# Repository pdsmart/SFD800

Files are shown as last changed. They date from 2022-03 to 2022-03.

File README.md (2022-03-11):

# SFD800
A Floppy Disk Interface card for the Sharp MZ series of machines (MZ-80B/MZ-800/MZ-1500/MZ-2000/MZ-2200).

This project reproduces an iconic floppy disk interface card from the 1980's. As floppy disks were expensive in those days, not many interface cards or floppy 
disk drives existed and even fewer survived. As the Sharp MZ series machines, like many of the old computers, are still used and in many ways making a comeback,
the need for a floppy disk interface is needed in order to use the machines.

Please see my website, https://eaw.app for more documentation and any recent updates. This interface has been well tested and used in many machines, a validated design.

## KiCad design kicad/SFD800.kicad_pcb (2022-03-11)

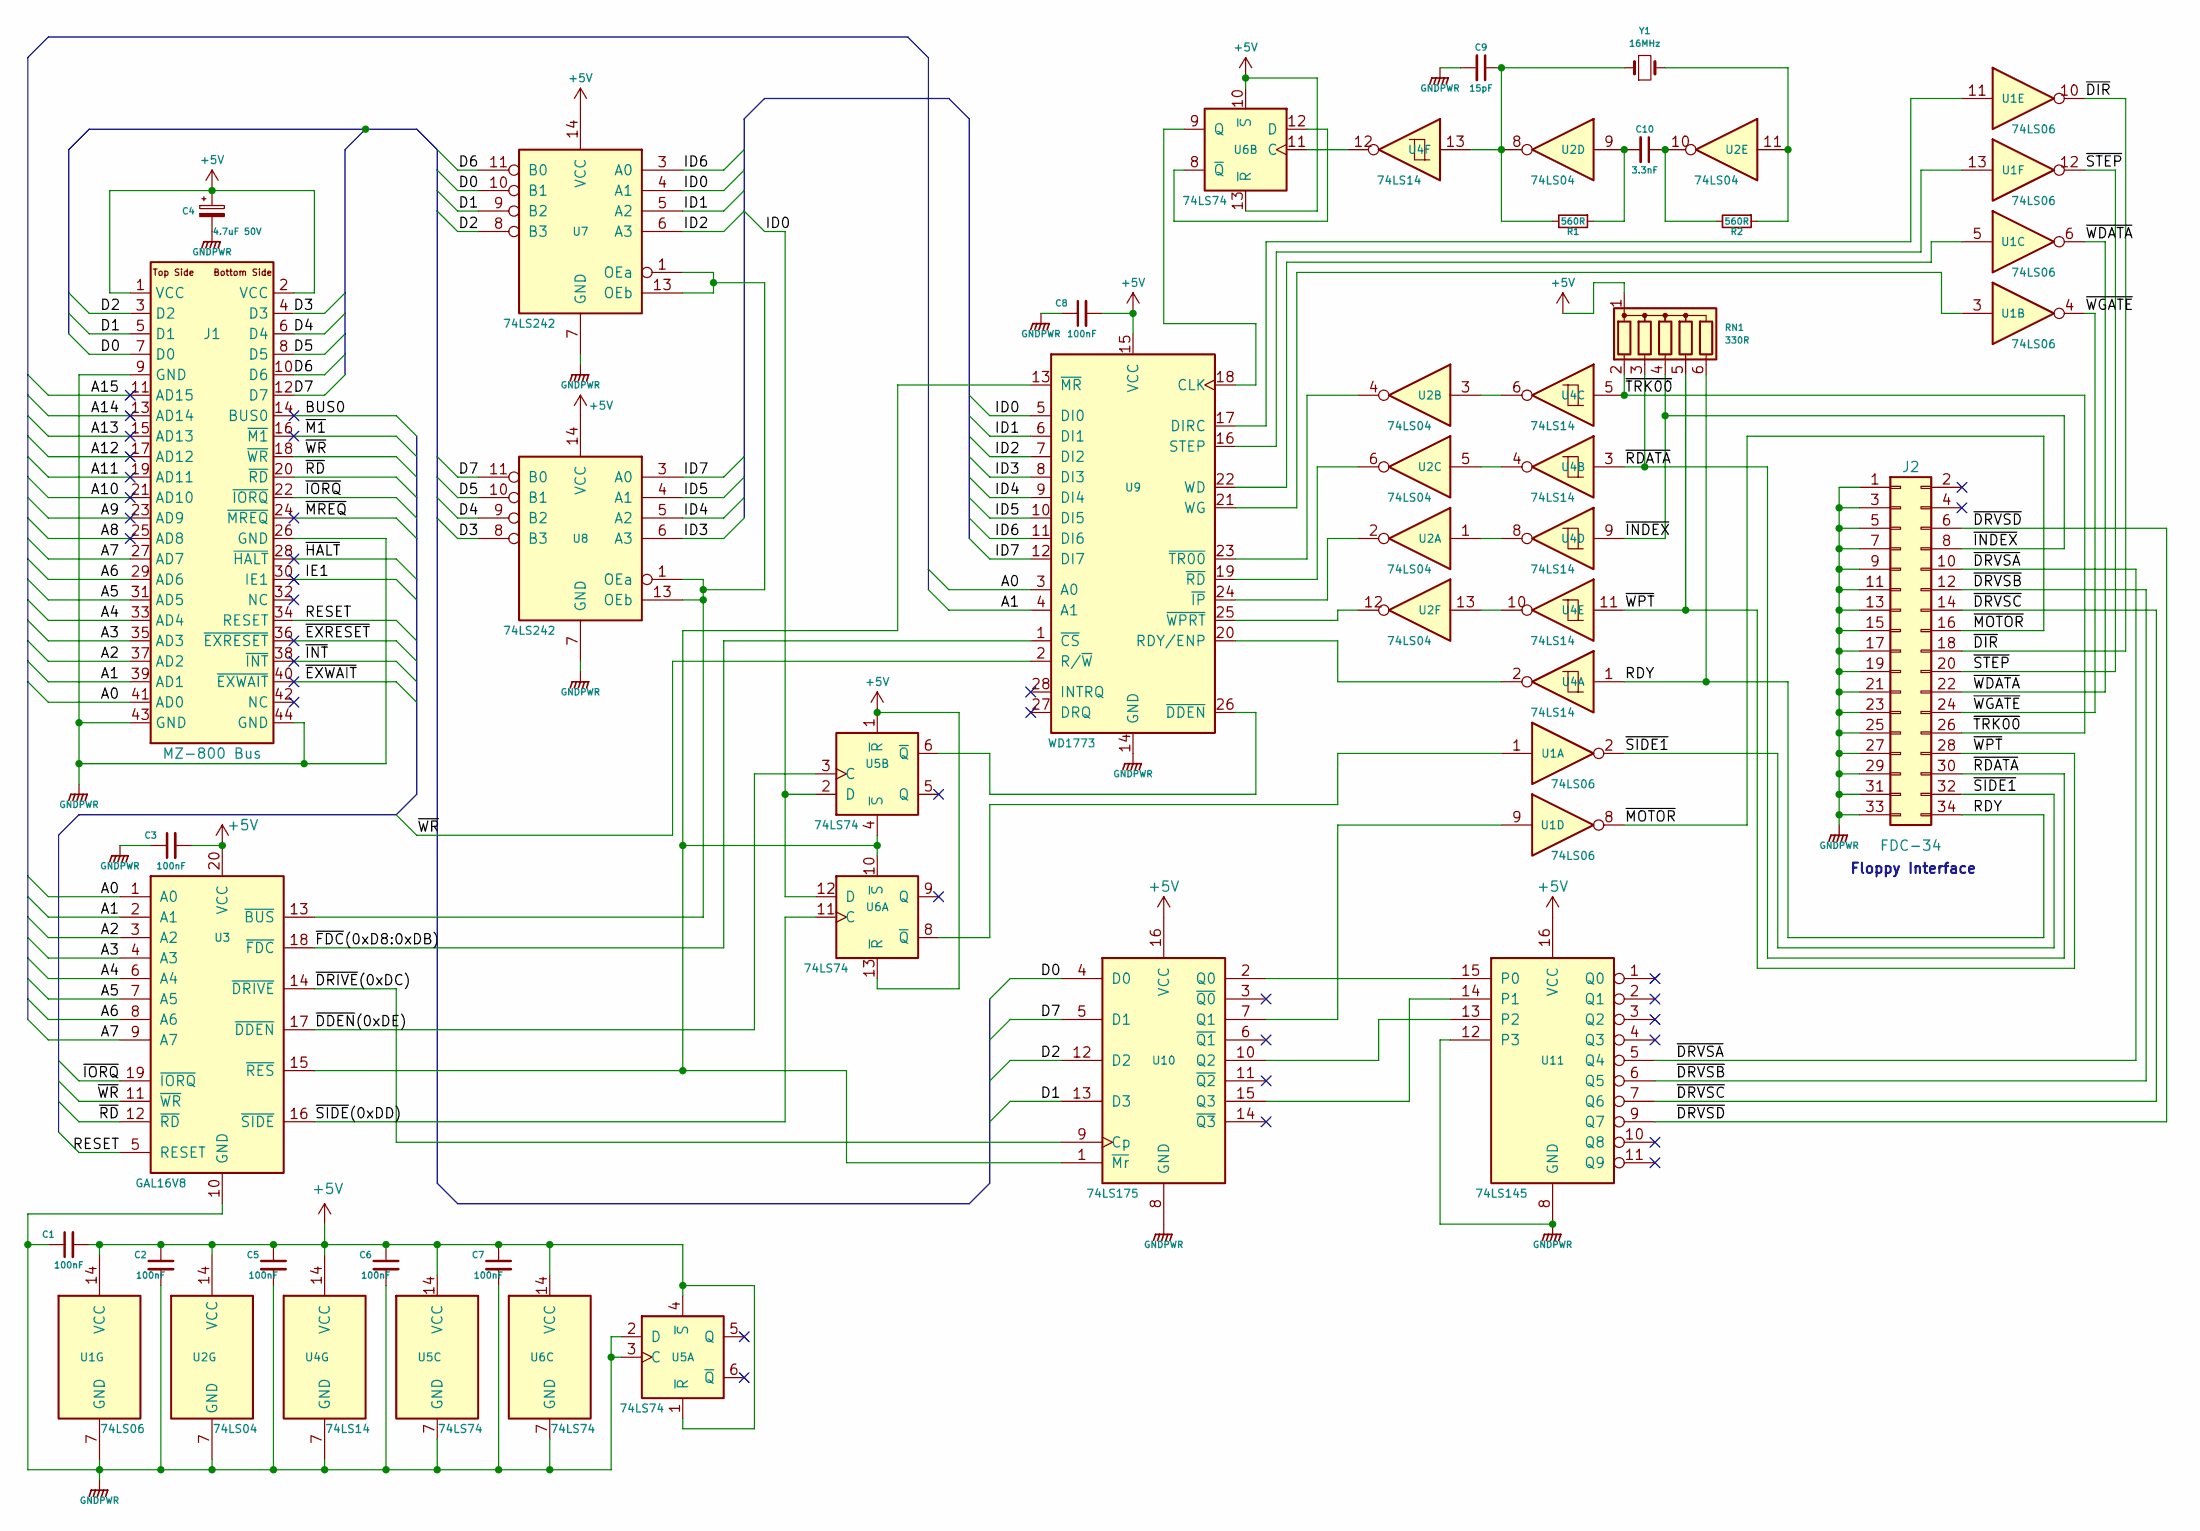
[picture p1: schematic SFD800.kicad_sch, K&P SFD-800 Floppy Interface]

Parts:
C1, C2, C3, C5, C6, C7, C8: 100nF; C_Disc_D5.0mm_W2.5mm_P2.50mm
C4: 4.7uF 50V; C_Disc_D5.0mm_W2.5mm_P2.50mm
C9: 15pF; C_Disc_D5.0mm_W2.5mm_P2.50mm
C10: 3.3nF; C_Disc_D5.0mm_W2.5mm_P2.50mm
J1: MZ-800 Bus; BUS_MZ800
J2: FDC-34; IDC-Header_2x17_P2.54mm_Horizontal_Lock_SFD800
R1, R2: 560R; R_Axial_DIN0204_L3.6mm_D1.6mm_P5.08mm_Horizontal
RN1: 330R; R_Array_SIP6
U1: 74LS06; DIP-14_W7.62mm
U2: 74LS04; DIP-14_W7.62mm
U3: GAL16V8; DIP-20_W7.62mm
U4: 74LS14; DIP-14_W7.62mm
U5, U6: 74LS74; DIP-14_W7.62mm
U7, U8: 74LS242; DIP-14_W7.62mm
U9: WD1773; DIP-28_W15.24mm
U10: 74LS175; DIP-16_W7.62mm
U11: 74LS145; DIP-16_W7.62mm
Y1: 16MHz; Crystal_HC18-U_Horizontal

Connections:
+5V: C1.2, C2.1, C3.2, C4.1, C5.1, C6.1, C7.1, C8.2, J1.1 (VCC), J1.2 (VCC), RN1.1 (common), U1.14 (VCC), U2.14 (VCC), U3.20 (VCC), U4.14 (VCC), U5.1 (~R), U5.4 (~S), U5.13 (~R), U5.14 (VCC), U6.1 (~R), U6.10 (~S), U6.13 (~R), U6.14 (VCC), U7.14 (VCC), U8.14 (VCC), U9.15 (VCC), U10.16 (VCC), U11.16 (VCC)
/A0: J1.41 (AD0), U3.1 (A0), U9.3 (A0)
/A1: J1.39 (AD1), U3.2 (A1), U9.4 (A1)
/A2: J1.37 (AD2), U3.3 (A2)
/A3: J1.35 (AD3), U3.4 (A3)
/A4: J1.33 (AD4), U3.6 (A4)
/A5: J1.31 (AD5), U3.7 (A5)
/A6: J1.29 (AD6), U3.8 (A6)
/A7: J1.27 (AD7), U3.9 (A7)
/A8: J1.25 (AD8)
/A9: J1.23 (AD9)
/A10: J1.21 (AD10)
/A11: J1.19 (AD11)
/A12: J1.17 (AD12)
/A13: J1.15 (AD13)
/A14: J1.13 (AD14)
/A15: J1.11 (AD15)
/BUS0: J1.14 (BUS0)
/D0: J1.7 (D0), U7.10 (B1), U10.4 (D0)
/D1: J1.5 (D1), U7.9 (B2), U10.13 (D3)
/D2: J1.3 (D2), U7.8 (B3), U10.12 (D2)
/D3: J1.4 (D3), U8.8 (B3)
/D4: J1.6 (D4), U8.9 (B2)
/D5: J1.8 (D5), U8.10 (B1)
/D6: J1.10 (D6), U7.11 (B0)
/D7: J1.12 (D7), U8.11 (B0), U10.5 (D1)
/ID0: U5.12 (D), U6.2 (D), U7.4 (A1), U9.5 (DI0)
/ID1: U7.5 (A2), U9.6 (DI1)
/ID2: U7.6 (A3), U9.7 (DI2)
/ID3: U8.6 (A3), U9.8 (DI3)
/ID4: U8.5 (A2), U9.9 (DI4)
/ID5: U8.4 (A1), U9.10 (DI5)
/ID6: U7.3 (A0), U9.11 (DI6)
/ID7: U8.3 (A0), U9.12 (DI7)
/IE1: J1.30 (IE1)
/RESET: J1.34 (RESET), U3.5 (RESET)
/~EXRESET: J1.36 (~EXRESET)
/~EXWAIT: J1.40 (~EXWAIT)
/~HALT: J1.28 (~HALT)
/~INT: J1.38 (~INT)
/~IORQ: J1.22 (~IORQ), U3.19 (~IORQ)
/~M1: J1.16 (~M1)
/~MREQ: J1.24 (~MREQ)
/~RD: J1.20 (~RD), U3.12 (~RD)
/~WR: J1.18 (~WR), U3.11 (~WR), U9.2 (R/~W)
GNDPWR: C1.1, C2.2, C3.1, C4.2, C5.2, C6.2, C7.2, C8.1, C9.2, J1.9 (GND), J1.26 (GND), J1.43 (GND), J1.44 (GND), J2.1, J2.3, J2.5, J2.7, J2.9, J2.11, J2.13, J2.15, J2.17, J2.19, J2.21, J2.23, J2.25, J2.27, J2.29, J2.31, J2.33, U1.7 (GND), U2.7 (GND), U3.10 (GND), U4.7 (GND), U5.2 (D), U5.3 (C), U5.7 (GND), U6.7 (GND), U7.7 (GND), U8.7 (GND), U9.14 (GND), U10.8 (GND), U11.8 (GND), U11.12 (P3)
unnamed: C9.1, R1.2, U2.8, U4.13, Y1.1
unnamed: C10.1, R2.2, U2.10
unnamed: C10.2, R1.1, U2.9
unnamed: J2.6, U11.9 (Q7)
unnamed: J2.8, RN1.4 (R3), U4.9
unnamed: J2.10, U11.5 (Q4)
unnamed: J2.12, U11.6 (Q5)
unnamed: J2.14, U11.7 (Q6)
unnamed: J2.16, U1.8
unnamed: J2.18, U1.10
unnamed: J2.20, U1.12
unnamed: J2.22, U1.6
unnamed: J2.24, U1.4
unnamed: J2.26, RN1.2 (R1), U4.5
unnamed: J2.28, RN1.5 (R4), U4.11
unnamed: J2.30, RN1.3 (R2), U4.3
unnamed: J2.32, U1.2
unnamed: J2.34, RN1.6 (R5), U4.1
unnamed: R2.1, U2.11, Y1.2
unnamed: U1.1, U5.8 (~Q)
unnamed: U1.3, U9.21 (WG)
unnamed: U1.5, U9.22 (WD)
unnamed: U1.9, U10.7 (Q1)
unnamed: U1.11, U9.17 (DIRC)
unnamed: U1.13, U9.16 (STEP)
unnamed: U2.1, U4.8
unnamed: U2.2, U9.24 (~IP)
unnamed: U2.3, U4.6
unnamed: U2.4, U9.23 (~TR00)
unnamed: U2.5, U4.4
unnamed: U2.6, U9.19 (~RD)
unnamed: U2.12, U9.25 (~WPRT)
unnamed: U2.13, U4.10
unnamed: U3.13 (~BUS), U7.1 (OEa), U7.13 (OEb), U8.1 (OEa), U8.13 (OEb)
unnamed: U3.16 (~SIDE), U5.11 (C)
unnamed: U3.17 (~DDEN), U6.3 (C)
unnamed: U3.18 (~FDC), U9.1 (~CS)
unnamed: U4.2, U9.20 (RDY/ENP)
unnamed: U4.12, U6.11 (C)
unnamed: U6.6 (~Q), U9.26 (~DDEN)
unnamed: U6.9 (Q), U9.18 (CLK)
unnamed: U6.8 (~Q), U6.12 (D)
unnamed: U3.15 (~RES), U5.10 (~S), U6.4 (~S), U9.13 (~MR), U10.1 (~Mr)
unnamed: U10.2 (Q0), U11.15 (P0)
unnamed: U3.14 (~DRIVE), U10.9 (Cp)
unnamed: U10.10 (Q2), U11.13 (P2)
unnamed: U10.15 (Q3), U11.14 (P1)

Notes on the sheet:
Floppy Interface

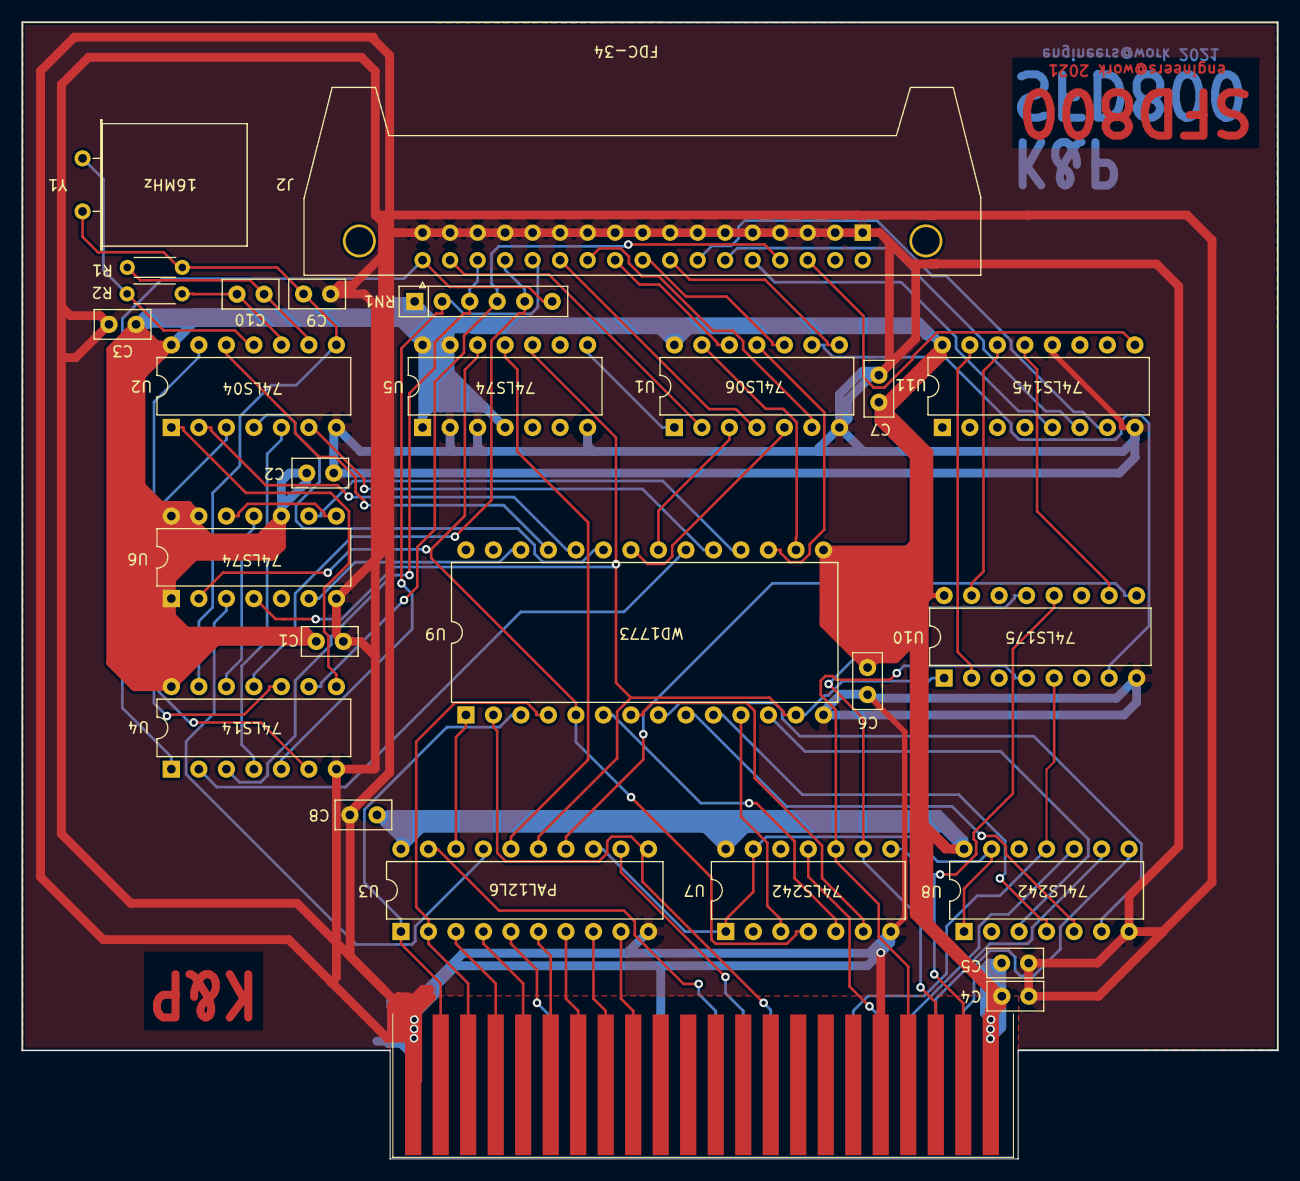
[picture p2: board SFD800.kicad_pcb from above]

Board: 2 copper layers, 116.0 x 105.0 mm, 27 parts (0 on the bottom side), 77 nets.
